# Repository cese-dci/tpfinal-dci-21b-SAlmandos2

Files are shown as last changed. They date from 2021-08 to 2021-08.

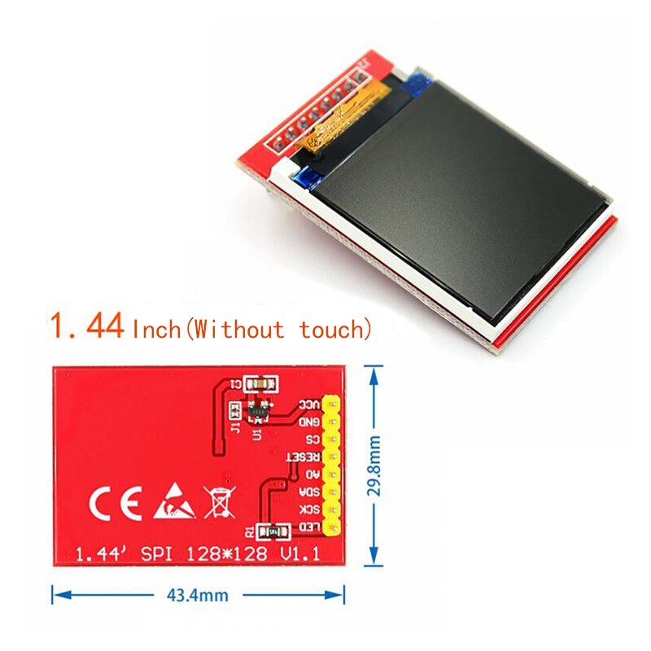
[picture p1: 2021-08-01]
doc/propuesta/TFT_dimensions.jpg

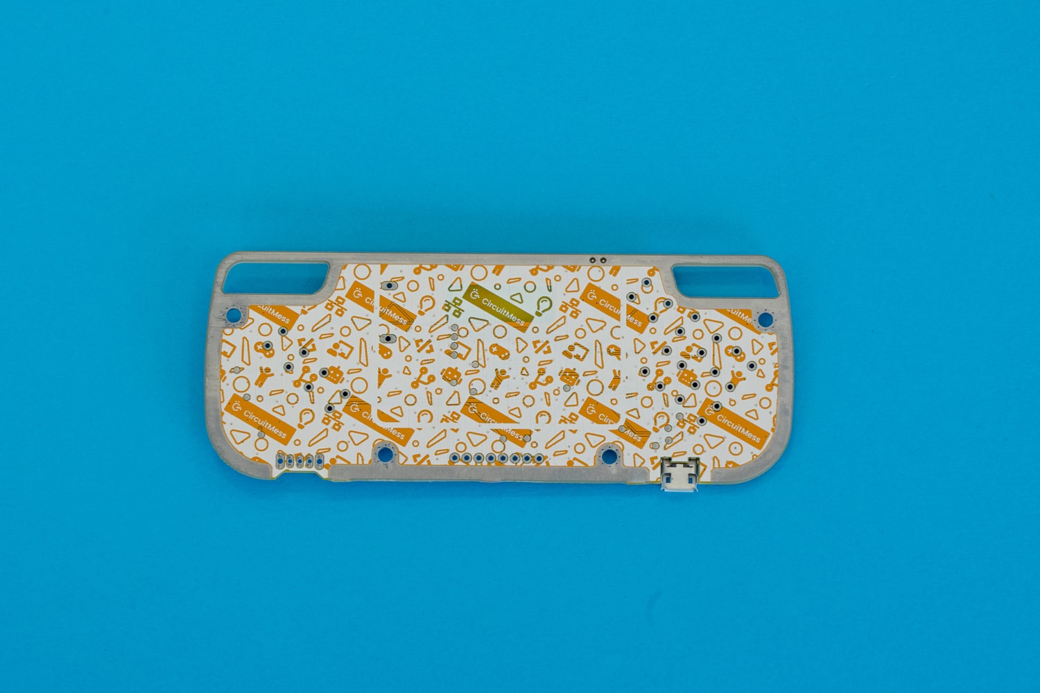
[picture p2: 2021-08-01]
doc/propuesta/Trasera.jpg

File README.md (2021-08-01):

## Trabajo práctico final de la asignatura DCI ##
Este repositorio contiene el trabajo práctico final para la asignatura de Diseño de Circuitos Impresos de la carrera de posgrado de FIUBA.

* Autor: Santiago Nicolas Almandos Marinzulich
* Título corto del trabajo:  Replica Nibble
* Descripción:  Nibble es una consola de videojuegos educacional hecha por vos mismo

## Licencia de este trabajo ##

Este trabajo se encuentra bajo licencia [GNU GPL 3.0](../gpl-3.0.txt)

## Estructura del TP FINAL ##

Se propone y se pide utilizar la siguiente estructura.

* doc: Toda la información sobre el circuito, principalmente de autoría o procesamiento propio. Por ejemplo:
  * Notas de ingeniería propias.
  * Notas de aplicación propias.
  * Estudios previos, estado del arte, resumen de las investigaciones.
  * Notas con cálculos.
  * Dibujos adicionales.
  * Fotos de los prototipos.
  * Presupuestos, cotizaciones.
* info: Toda la iformación recolectada, principalmente de terceros, como por ejemplo:
  * Hojas de datos.
  * Notas de aplicación.
  * Info de productos comerciales.
  * Info en internet.
* pcb: Archivos de diseño esquemático y pcb.

Dependiendo la magnitud del proyecto, tendremos más o menos información en estos directorios. 
Revisar los README.md en cada directorio para conocer las pautas de cada uno para este TP.

NOTA: El alumno puede y debe borrar de este archivo todo lo que considere necesario, por ejemplo las aclaraciones del docente y esta misma nota.

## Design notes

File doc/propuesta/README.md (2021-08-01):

## Propuesta ##

El circuito y diseño original fueron extraidos de la pagina de su creador, [CIRCUITMESS](https://circuitmess.com/resources/guides/en/nibble-build-guide)

En este directorio debe ir OBLIGATORIAMENTE la información que se presentó al momento de acordar la propuesta de TP con el docente. Es decir:
* Fotos e imágenes de las placas de ambos lados si es una réplica. 
* Fotos e imágenes de los prototipos cableados o pruebas si es un trabajo de tesis.
* Urls o info de origen. 
* Circuito esquemático de referencia (si es una réplica) o borrador si es un trabajo de tesis.
* Resumen de la función u objetivo del circuito si es un trabajo de tesis.
* Cualquier otra nota que se haya usado para definir el TP en el formulario de propuesta.

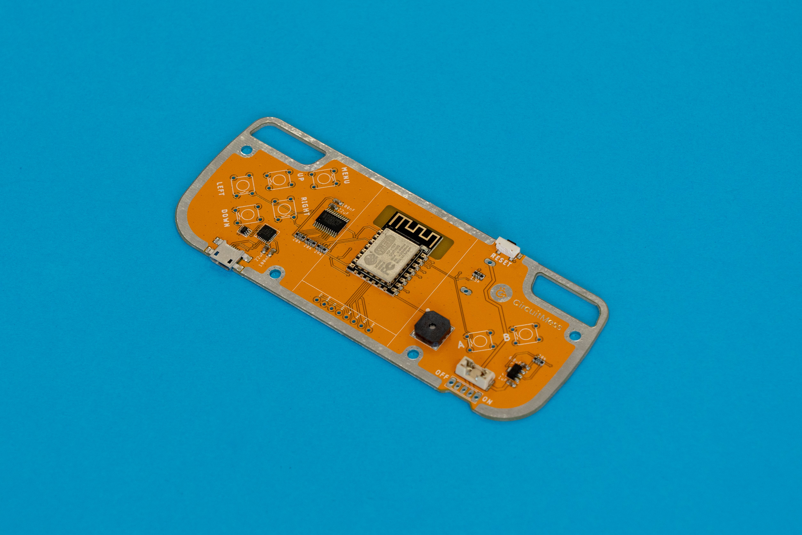
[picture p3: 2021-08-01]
doc/propuesta/Frontal2.jpeg

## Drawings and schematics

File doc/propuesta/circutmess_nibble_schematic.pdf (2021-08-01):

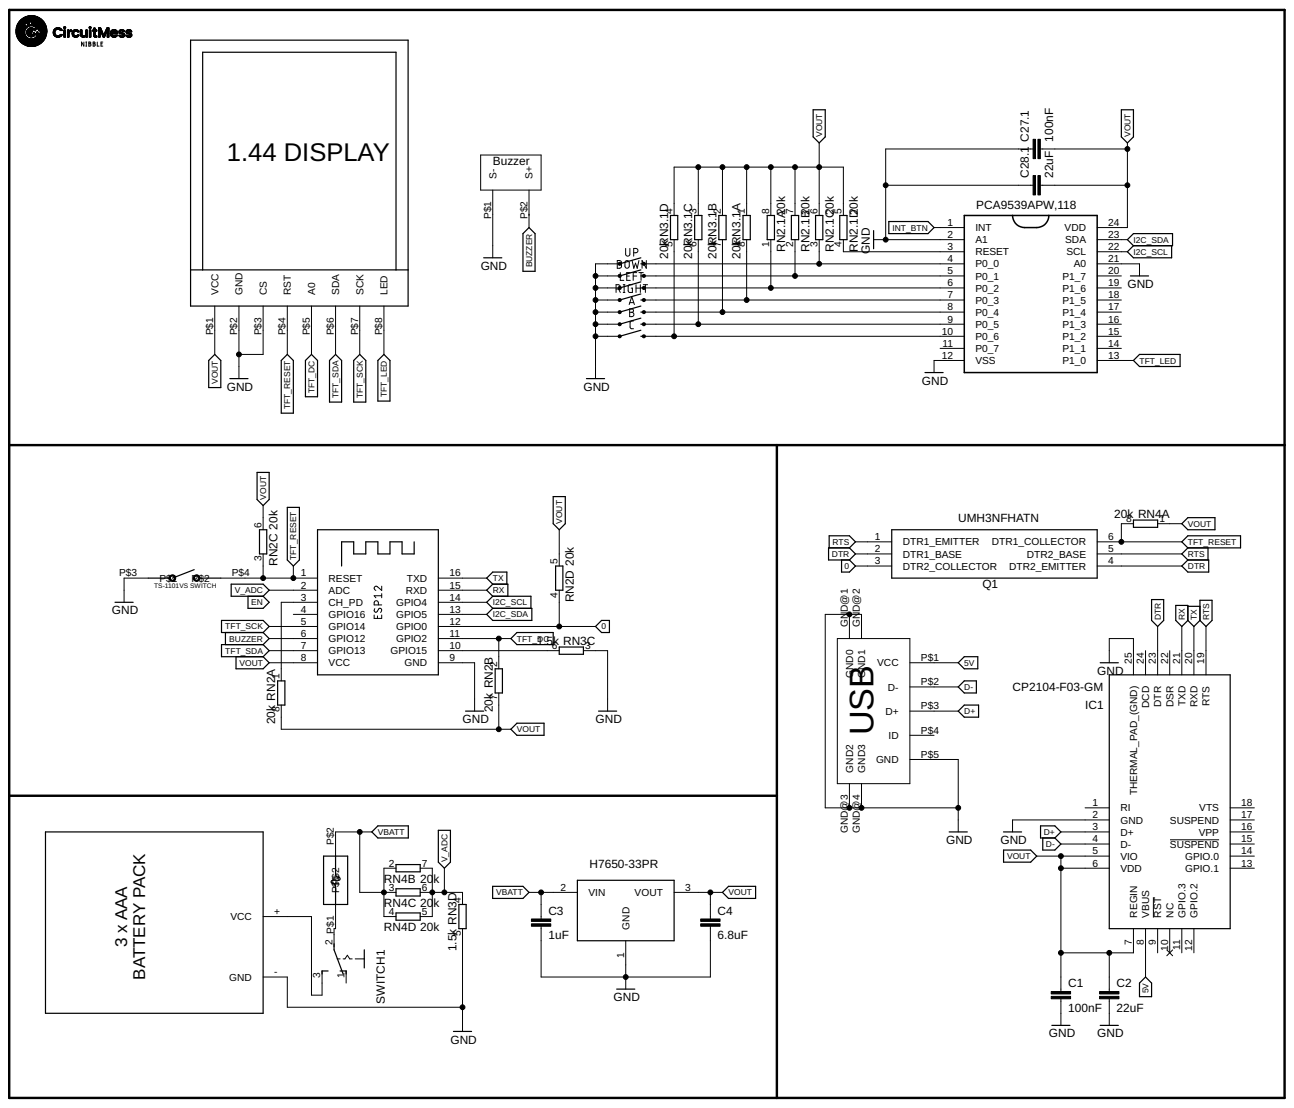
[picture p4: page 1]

GND3 GND@4 GND2 GND@3 GND1 GND@2 GND0 GND@1

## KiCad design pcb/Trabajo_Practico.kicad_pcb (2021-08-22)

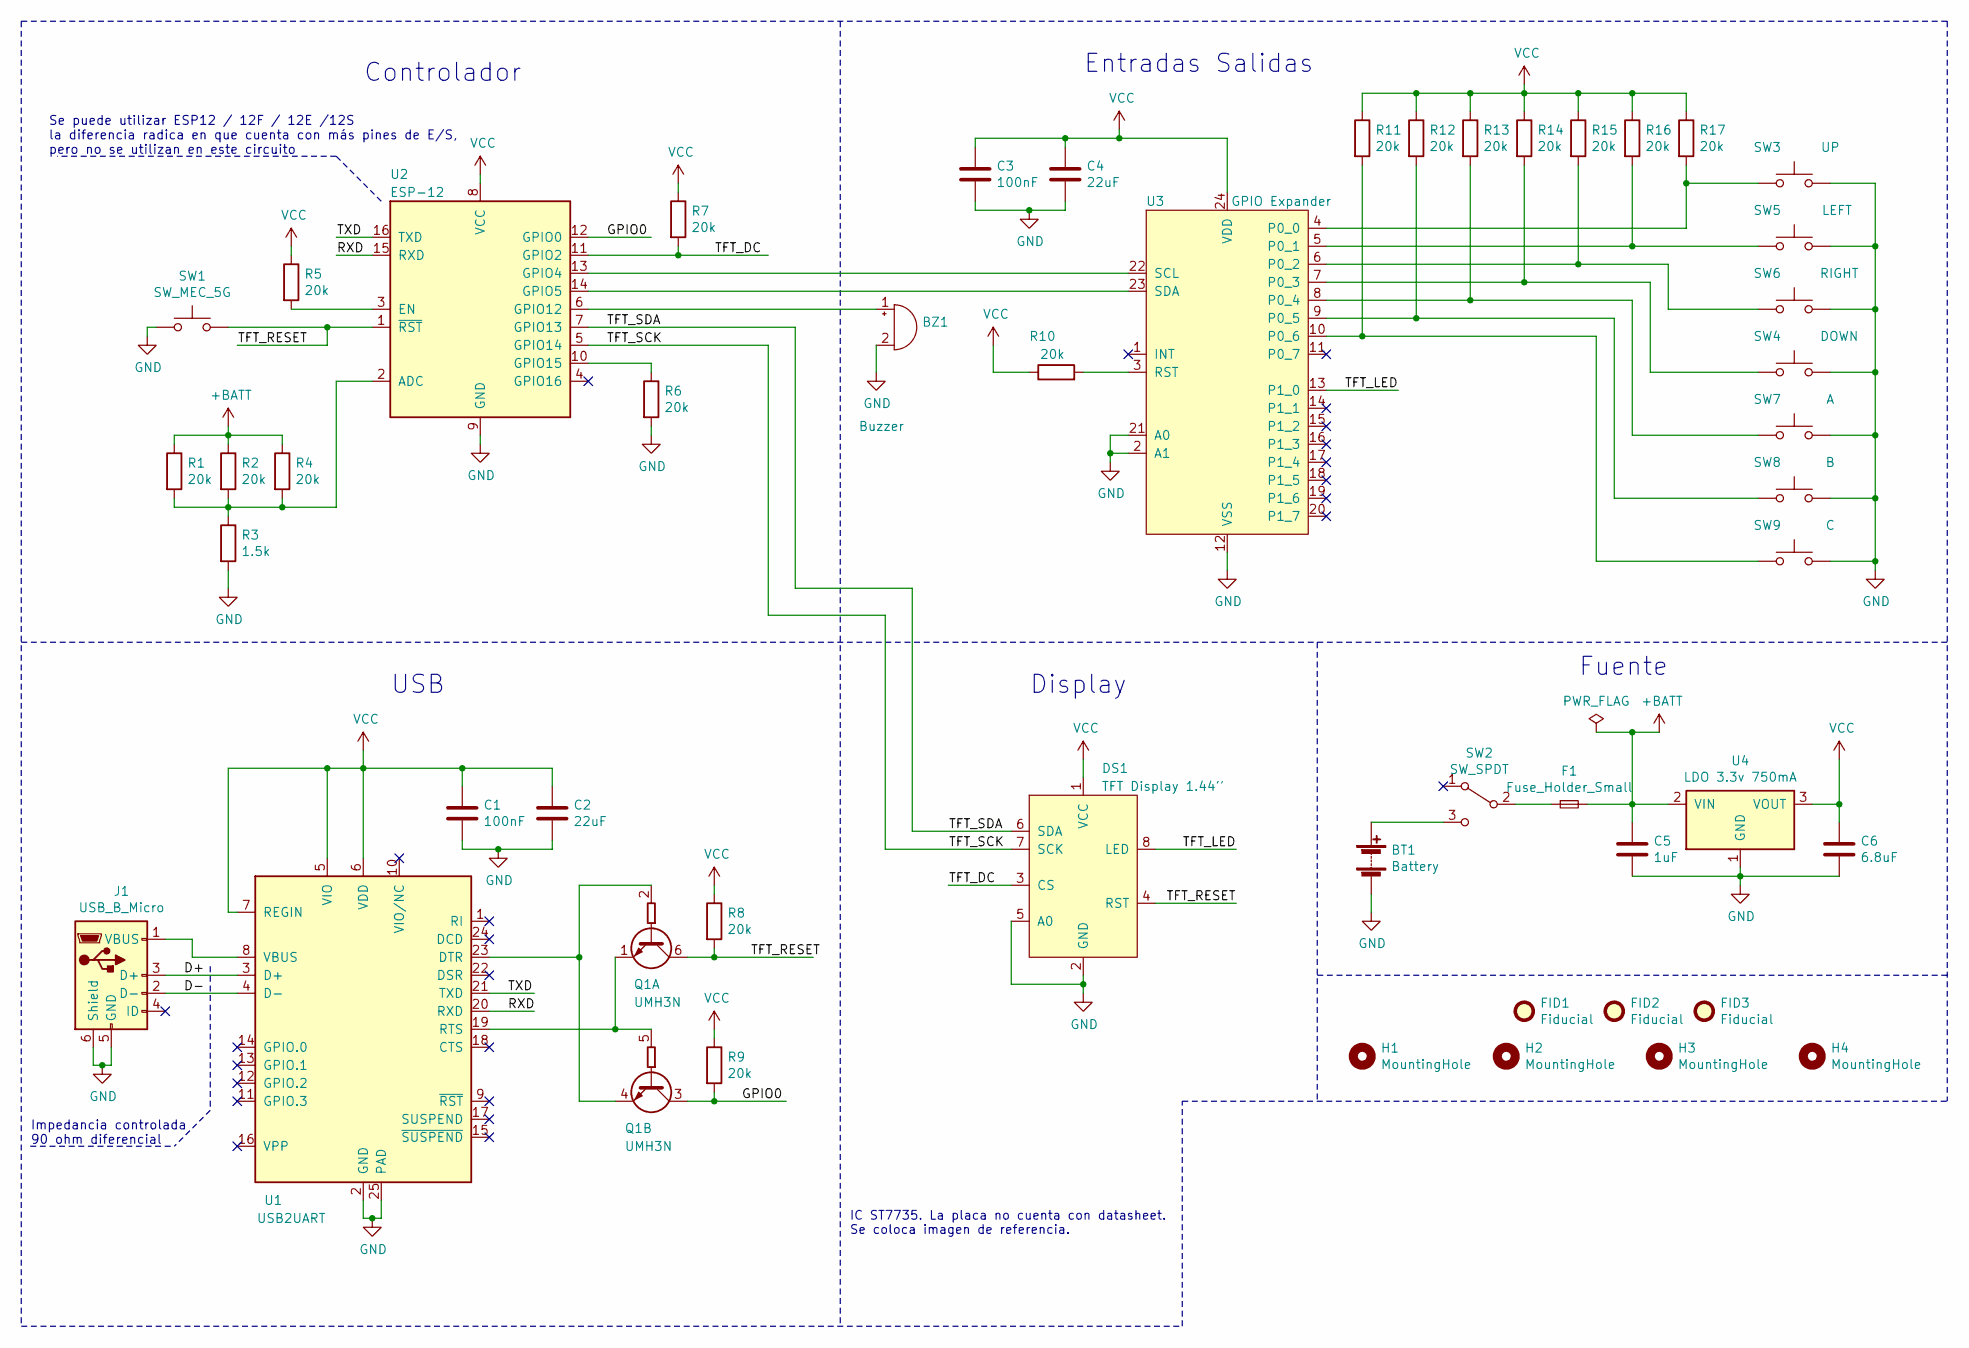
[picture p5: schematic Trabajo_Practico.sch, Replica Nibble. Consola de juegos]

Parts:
BT1: Battery; BatteryHolder_Keystone_2479_3xAAA
BZ1: Buzzer; MagneticBuzzer_CUI_CMT-8504-100-SMT; Manuf# CMT-8503-85B-SMT-TR; Mouser 490-CMT-850385BSMTTR
C1, C3: 100nF; C_0805_2012Metric
C2, C4: 22uF; C_0805_2012Metric
C5: 1uF; C_0805_2012Metric
C6: 6.8uF; C_0805_2012Metric
DS1: TFT Display 1.44''; TFT_1.44I_SPI; Manuf# ST7735_1.44_128x128_SPI
F1: Fuse_Holder_Small; Fuse_Holder_Littefuse_Nano; Manuf# 0154001.DRTL
FID1, FID2, FID3: Fiducial; Fiducial_1.5mm_Mask3mm
H1, H2, H3, H4: MountingHole; MountingHole_2.2mm_M2_Pad_Via
J1: USB_B_Micro; USB_Micro-B_Molex_47346-0001; Manuf# 10104110-0001LF; Mouser 649-10104110-0001LF
Q1: UMH3N; SOT-363_SC-70-6; Manuf# UMH3NFHATN; Mouser 755-UMH3NFHATN
R1, R2, R4, R5, R6, R7, R8, R9, R10, R11, R12, R13, R14, R15, R16, R17: 20k; R_0805_2012Metric
R3: 1.5k; R_0805_2012Metric
SW1: SW_MEC_5G; SW_Tactile_SPST_Angled_PTS645Vx31-2LFS
SW2: SW_SPDT; SW_CuK_JS202011AQN_DPDT_Angled
SW3: UP; SW_SPST_PTS645
SW4: DOWN; SW_SPST_PTS645
SW5: LEFT; SW_SPST_PTS645
SW6: RIGHT; SW_SPST_PTS645
SW7: A; SW_SPST_PTS645
SW8: B; SW_SPST_PTS645
SW9: C; SW_SPST_PTS645
U1: USB2UART; QFN-24-1EP_4x4mm_P0.5mm_EP2.6x2.6mm; Manuf# CP2104-F03-GM; Mouser 634-CP2104-F03-GM
U2: ESP-12; ESP-12E
U3: GPIO Expander; TSSOP-24_4.4x7.8mm_P0.65mm; Manuf# PCA9539APW,118; Mouser 771-PCA9539APW,118
U4: LDO 3.3v 750mA; SOT-89-3_Handsoldering; Manuf# H7650-33PR

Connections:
+BATT: C5.1, F1.2, R1.1, R2.1, R4.1, U4.2 (VIN)
/D+: J1.3 (D+), U1.3 (D+)
/D-: J1.2 (D-), U1.4 (D-)
/GPIO0: Q1.3 (C2), R9.2, U2.12 (GPIO0)
/RXD: U1.20 (RXD), U2.15 (RXD)
/TFT_DC: DS1.3 (CS), R7.2, U2.11 (GPIO2)
/TFT_LED: DS1.8 (LED), U3.13 (P1_0)
/TFT_RESET: DS1.4 (RST), Q1.6 (C1), R8.2, SW1.3 (B), SW1.4 (B), U2.1 (~RST)
/TFT_SCK: DS1.7 (SCK), U2.5 (GPIO14)
/TFT_SDA: DS1.6 (SDA), U2.7 (GPIO13)
/TXD: U1.21 (TXD), U2.16 (TXD)
GND: BT1.2 (-), BZ1.2 (+), C1.2, C2.2, C3.2, C4.2, C5.2, C6.2, DS1.2 (GND), DS1.5 (A0), J1.5 (GND), J1.6 (Shield), R3.2, R6.2, SW1.1 (A), SW1.2 (A), SW3.2, SW4.2, SW5.2, SW6.2, SW7.2, SW8.2, SW9.2, U1.2 (GND), U1.25 (PAD), U2.9 (GND), U3.2 (A1), U3.12 (VSS), U3.21 (A0), U4.1 (GND)
unnamed: BT1.1 (+), SW2.3 (C)
unnamed: BZ1.1 (-), U2.6 (GPIO12)
unnamed: F1.1, SW2.2 (B)
unnamed: J1.1 (VBUS), U1.8 (VBUS)
unnamed: Q1.1 (E1), Q1.5 (B2), U1.19 (RTS)
unnamed: Q1.2 (B1), Q1.4 (E2), U1.23 (DTR)
unnamed: R1.2, R2.2, R3.1, R4.2, U2.2 (ADC)
unnamed: R5.2, U2.3 (EN)
unnamed: R6.1, U2.10 (GPIO15)
unnamed: R10.2, U3.3 (RST)
unnamed: R11.2, SW9.1, U3.10 (P0_6)
unnamed: R12.2, SW8.1, U3.9 (P0_5)
unnamed: R13.2, SW7.1, U3.8 (P0_4)
unnamed: R14.2, SW4.1, U3.7 (P0_3)
unnamed: R15.2, SW6.1, U3.6 (P0_2)
unnamed: R16.2, SW5.1, U3.5 (P0_1)
unnamed: R17.2, SW3.1, U3.4 (P0_0)
unnamed: U2.13 (GPIO4), U3.22 (SCL)
unnamed: U2.14 (GPIO5), U3.23 (SDA)
VCC: C1.1, C2.1, C3.1, C4.1, C6.1, DS1.1 (VCC), R5.1, R7.1, R8.1, R9.1, R10.1, R11.1, R12.1, R13.1, R14.1, R15.1, R16.1, R17.1, U1.5 (VIO), U1.6 (VDD), U1.7 (REGIN), U2.8 (VCC), U3.24 (VDD), U4.3 (VOUT)

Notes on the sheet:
Controlador
Entradas Salidas
Display
USB
Fuente
IC ST7735. La placa no cuenta con datasheet. Se coloca imagen de referencia.
Se puede utilizar ESP12 / 12F / 12E /12S la diferencia radica en que cuenta con más pines de E/S, pero no se utilizan en este circuito
Impedancia controlada 90 ohm diferencial

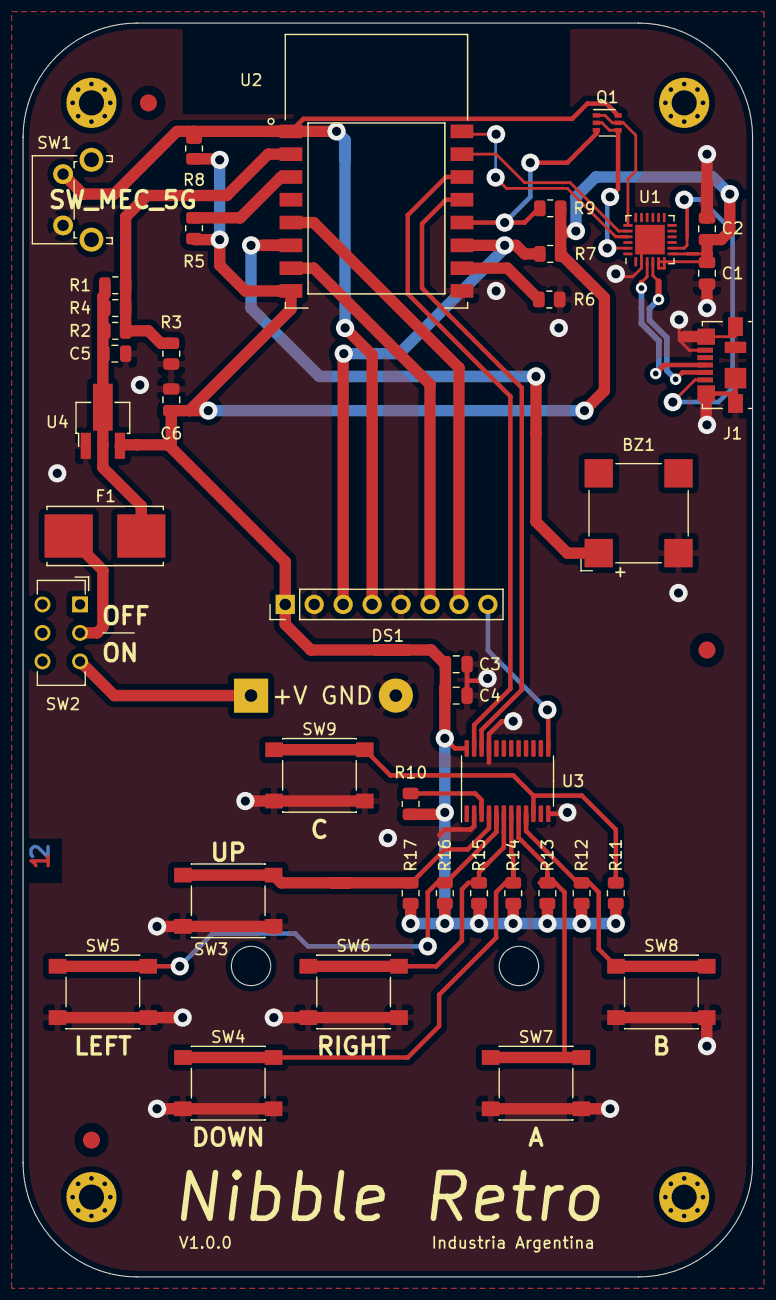
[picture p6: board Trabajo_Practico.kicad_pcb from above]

Board: 2 copper layers, 64.0 x 110.0 mm, 49 parts (1 on the bottom side), 32 nets.

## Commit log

2021-07-04 Agregado proyecto y esquematicos
    [Trabajo_Practico.kicad_pcb, Trabajo_Practico.sch]
2021-08-01 Actualizacion de documentos y esquematico
    [1.44in SPI LCD Module - No Glass.stp, 71071832.stp, CMT-8503-85B-SMT-TR.stp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]
2021-08-08 Updated PCB component place and board edge
    [Trabajo_Practico.kicad_pcb, Trabajo_Practico.sch]
2021-08-11 modified switch to SMD
    [Trabajo_Practico.kicad_pcb, Trabajo_Practico.sch, switch.stp]
2021-08-14 Routed and checked
    [Trabajo_Practico.kicad_pcb, Trabajo_Practico.sch]
2021-08-17 added all 3d shapes
    [1.44in SPI LCD Module - No Glass.stp, 71071832.stp, CMT-8503-85B-SMT-TR.stp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]
2021-08-22 Fix: clearance to 0.25 and values in schematic
    [Trabajo_Practico.kicad_pcb, Trabajo_Practico.sch]
2021-08-22 Fix: layer num on notes
    [Trabajo_Practico.kicad_pcb]
